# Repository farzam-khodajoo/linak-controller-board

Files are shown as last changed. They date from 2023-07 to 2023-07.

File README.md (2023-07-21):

## Introduction

Linak Controller Board is a small form factor pcb design which features ESP8266 for WIFI communication, this board is designed to control Hospital Bed with quad DC motors. 
(Kicad V6)

Each Motor uses 2 relays to change polarity and reverse rotation, also a linear voltage regulator is featured to power NodeMcu v3 board with small SPI pin connector on the side as extra utiltiy.

you can download schematic [here](https://github.com/farzam-khodajoo/linak-controller-board/blob/master/prints/Linak-controller.pdf).

## 3D views

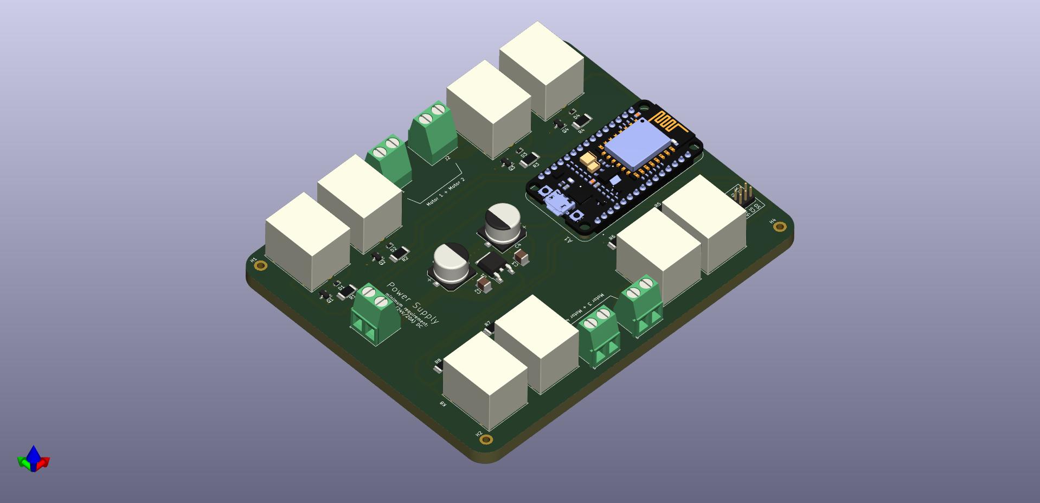
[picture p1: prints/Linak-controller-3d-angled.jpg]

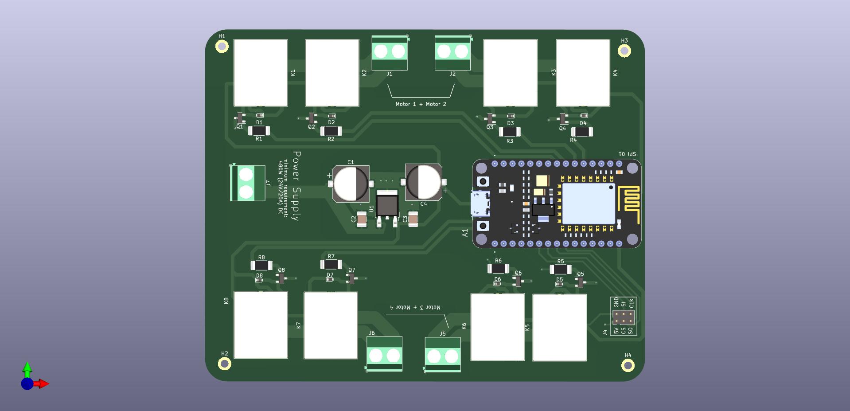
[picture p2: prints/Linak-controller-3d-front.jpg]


## PCB 
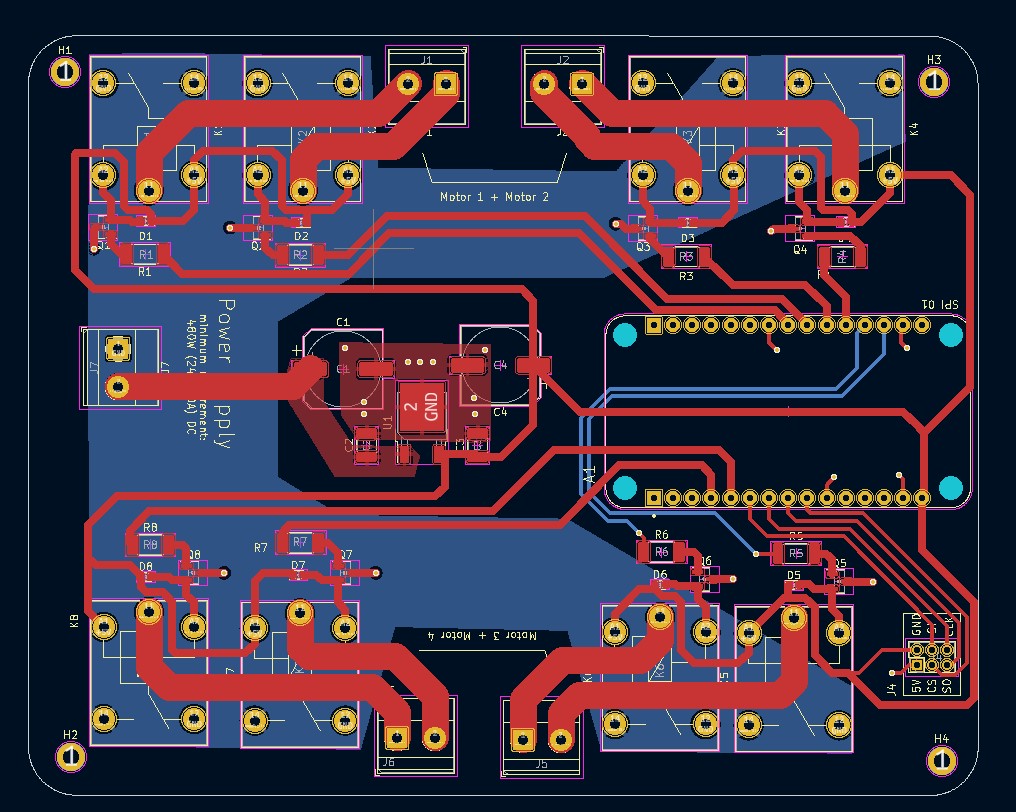
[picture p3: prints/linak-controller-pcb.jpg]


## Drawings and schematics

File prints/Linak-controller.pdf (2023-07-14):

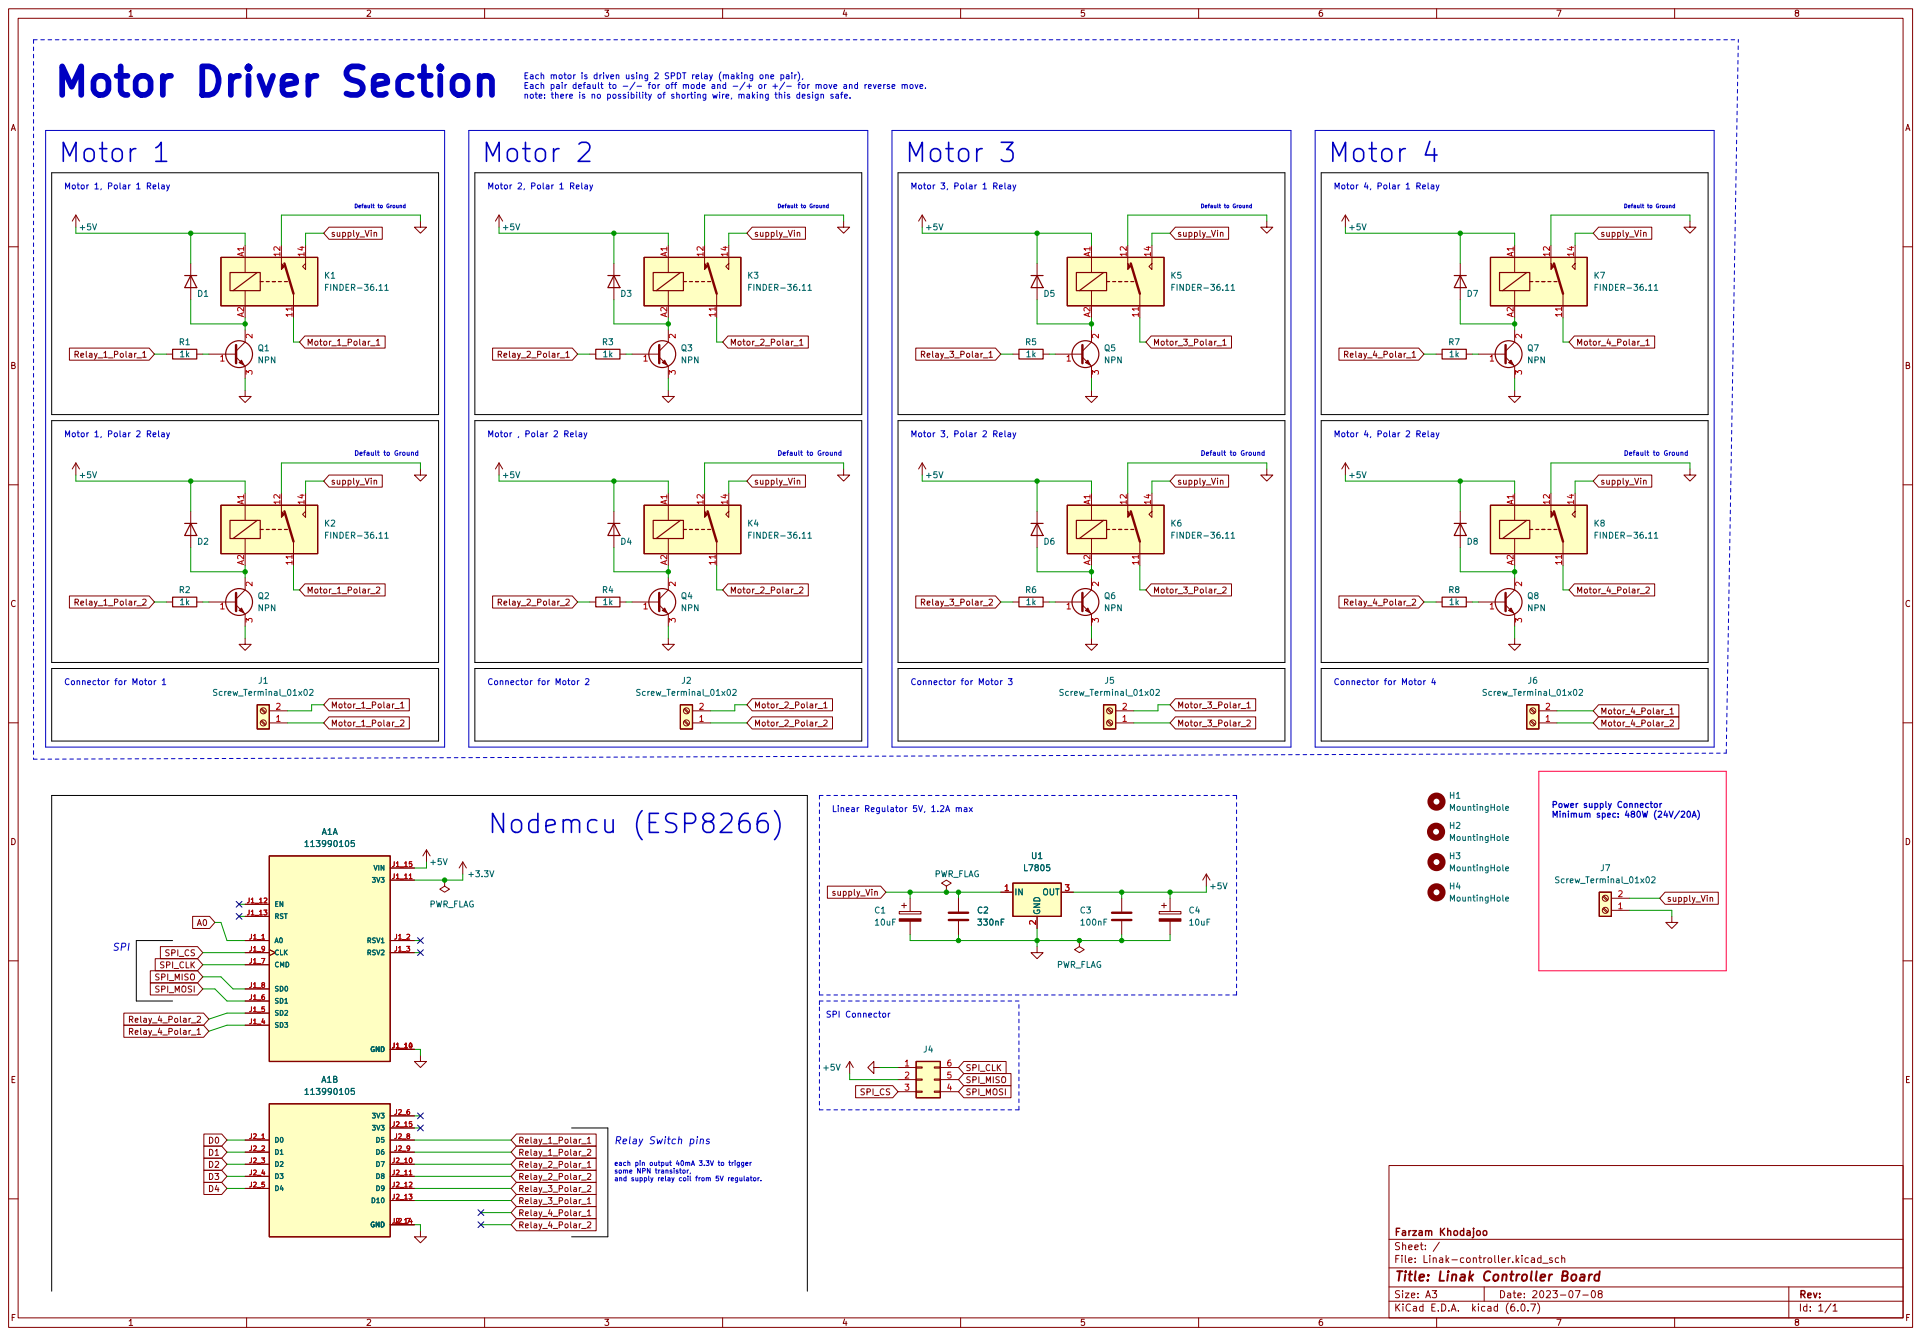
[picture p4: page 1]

Each pair default to -/- for off mode and -/+ or +/- for move and reverse move.
note: there is no possibility of shorting wire, making this design safe.
Motor 2

File: Linak-controller.kicad_sch Sheet: / Farzam Khodajoo H3MountingHole R6

each pin output 40mA 3.3V to trigger some NPN transistor, and supply relay coil from 5V regulator. Relay Switch pins

Id: 1/1 Title: Linak Controller Board

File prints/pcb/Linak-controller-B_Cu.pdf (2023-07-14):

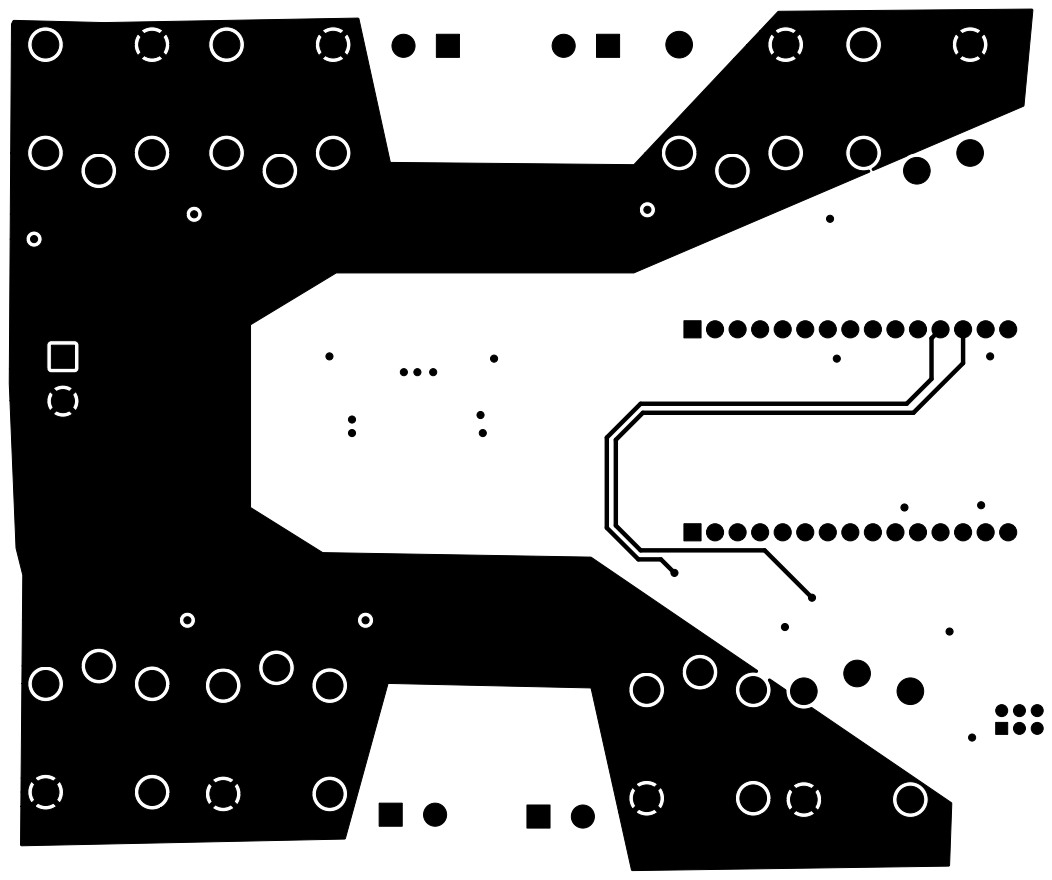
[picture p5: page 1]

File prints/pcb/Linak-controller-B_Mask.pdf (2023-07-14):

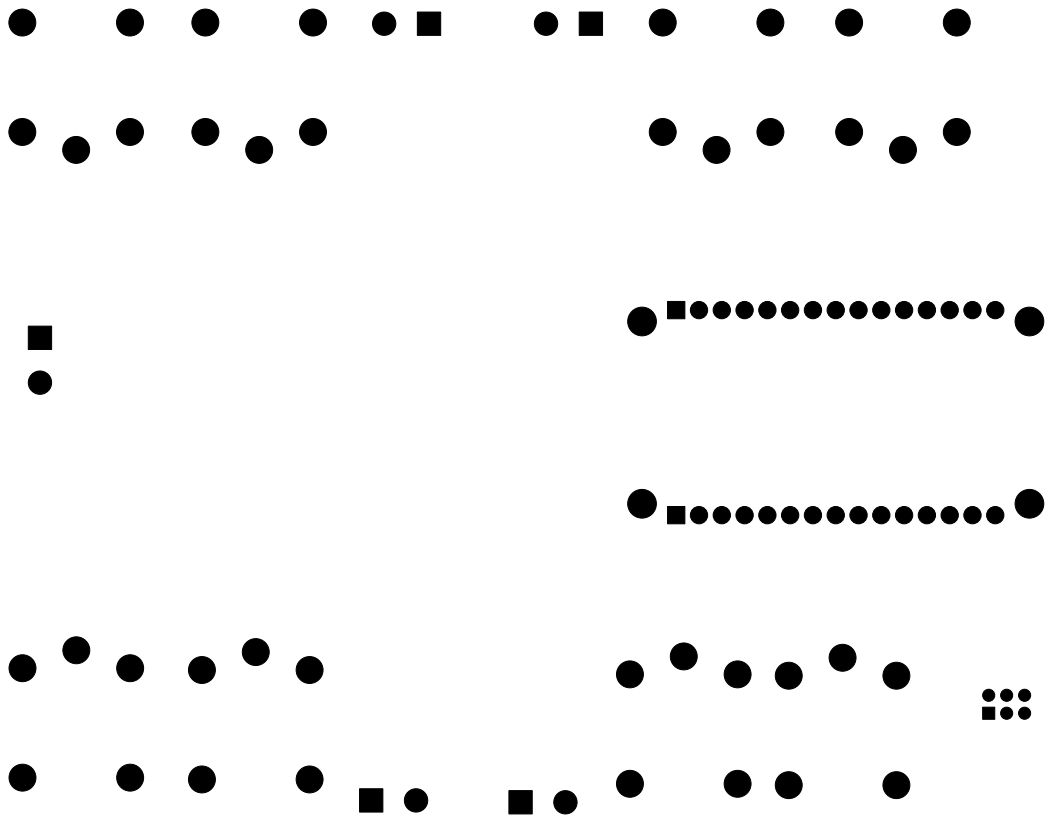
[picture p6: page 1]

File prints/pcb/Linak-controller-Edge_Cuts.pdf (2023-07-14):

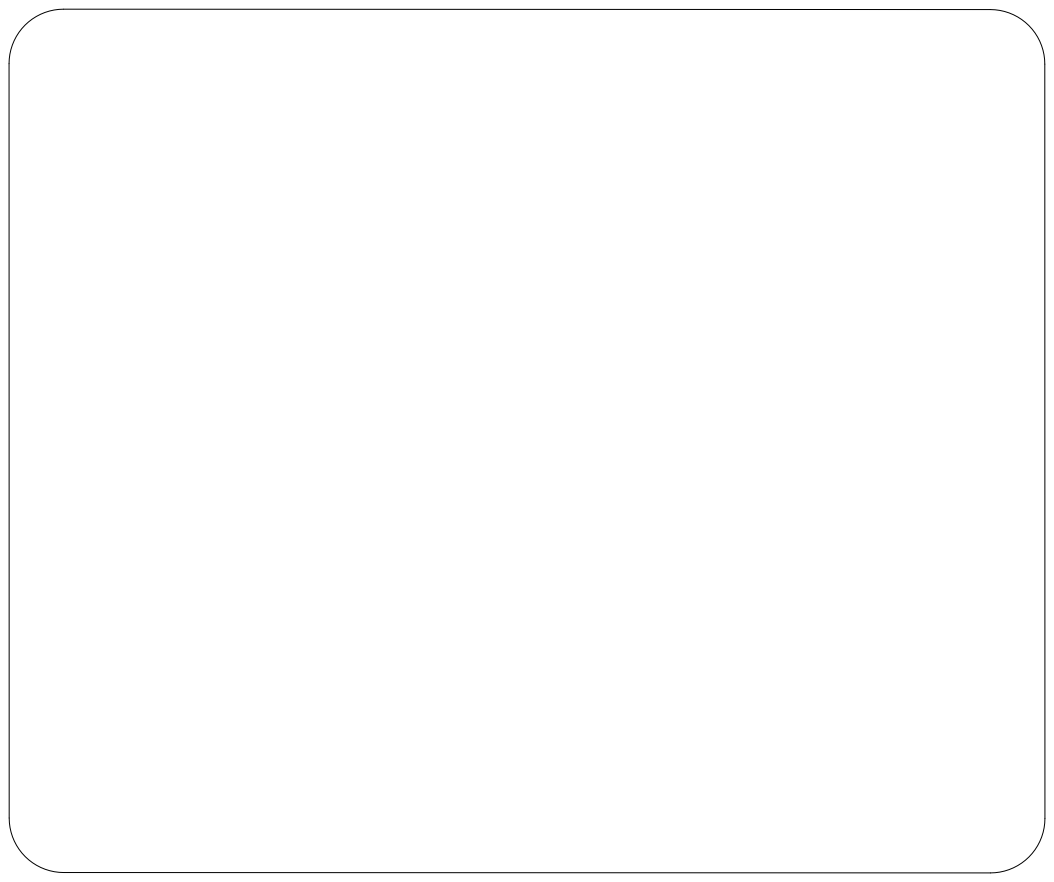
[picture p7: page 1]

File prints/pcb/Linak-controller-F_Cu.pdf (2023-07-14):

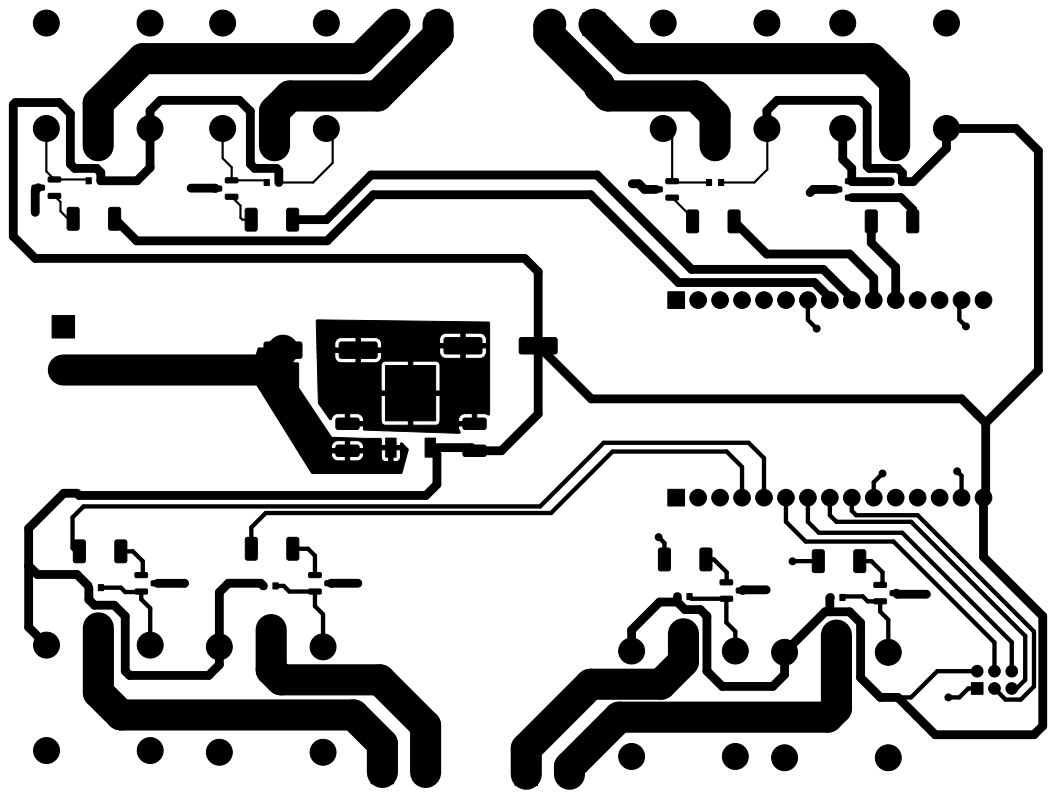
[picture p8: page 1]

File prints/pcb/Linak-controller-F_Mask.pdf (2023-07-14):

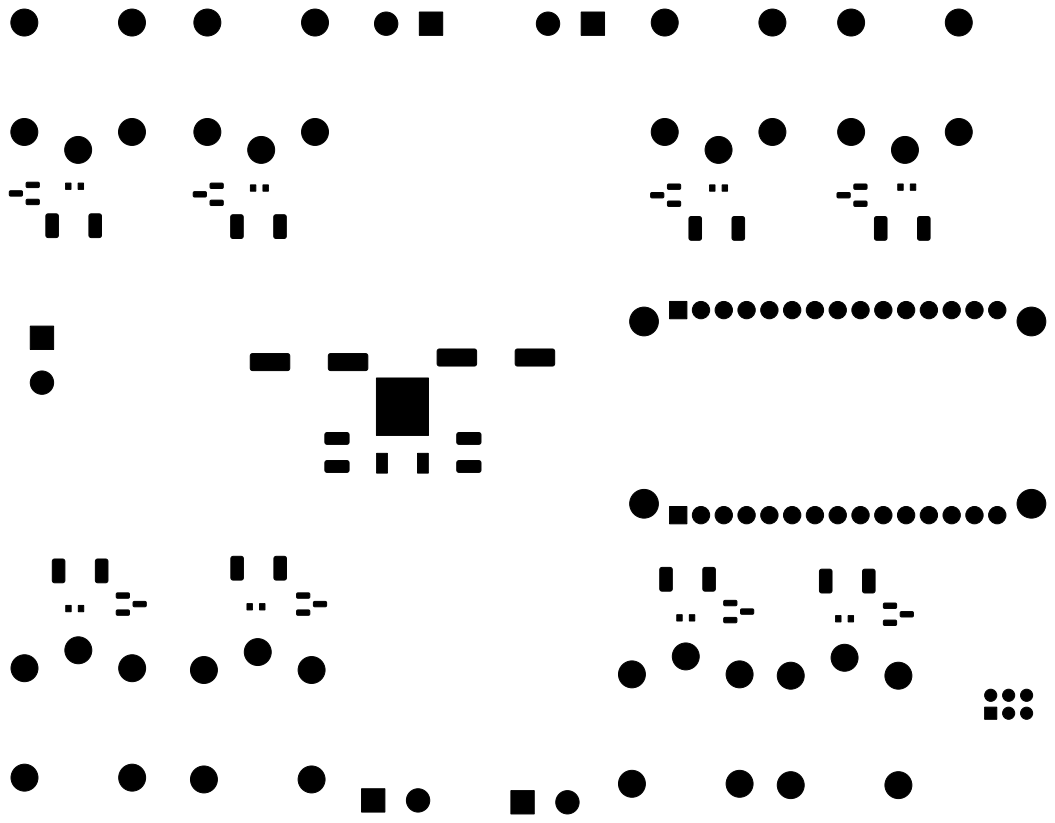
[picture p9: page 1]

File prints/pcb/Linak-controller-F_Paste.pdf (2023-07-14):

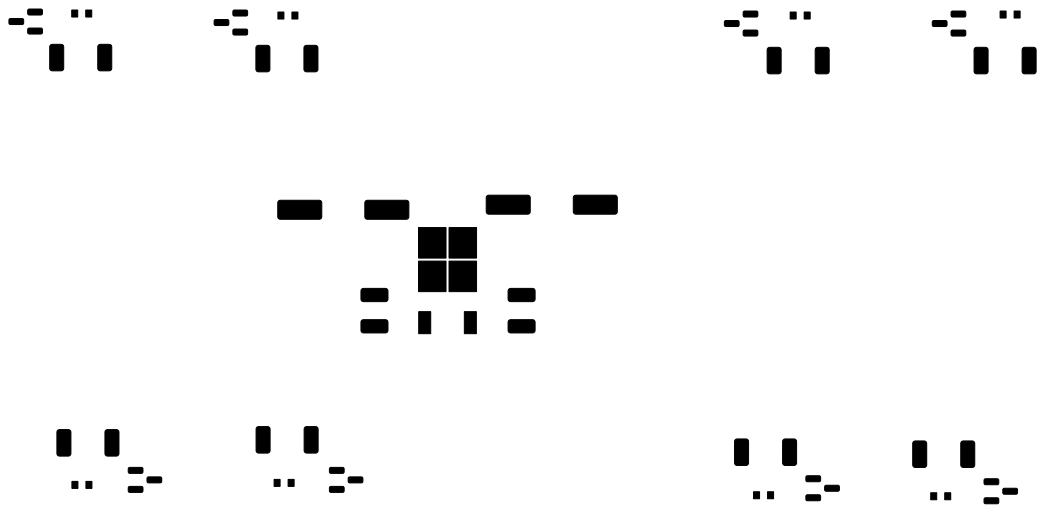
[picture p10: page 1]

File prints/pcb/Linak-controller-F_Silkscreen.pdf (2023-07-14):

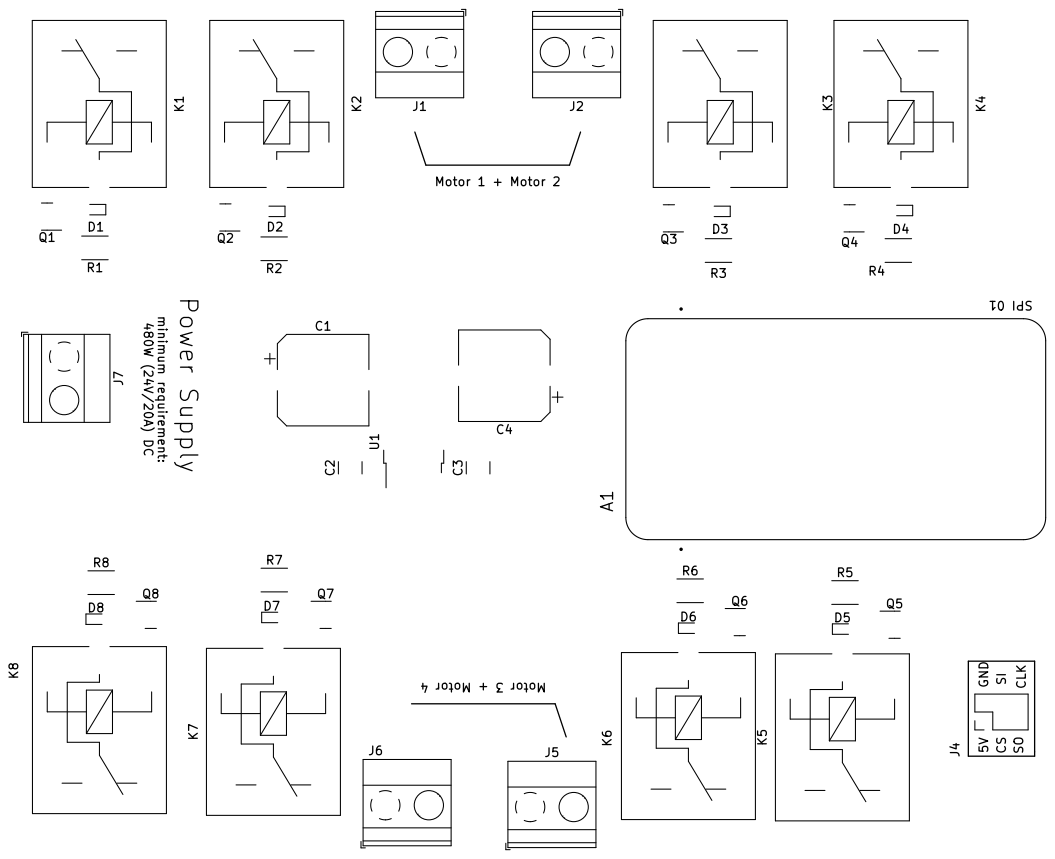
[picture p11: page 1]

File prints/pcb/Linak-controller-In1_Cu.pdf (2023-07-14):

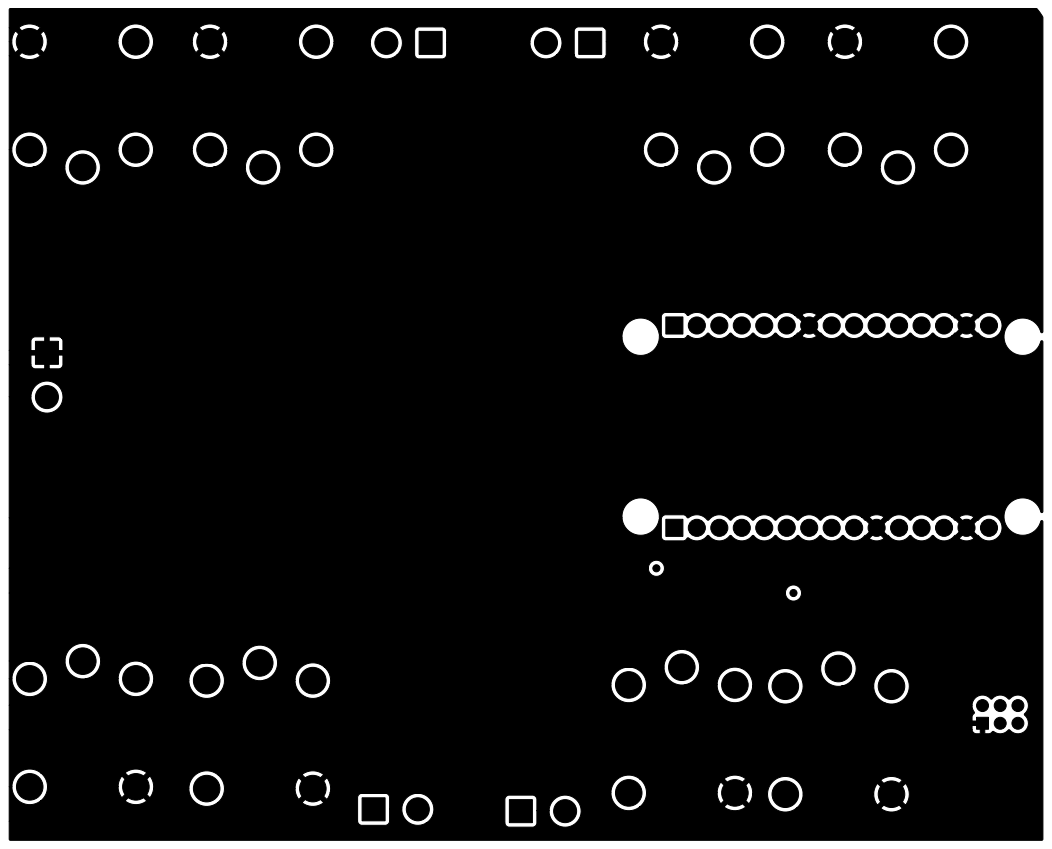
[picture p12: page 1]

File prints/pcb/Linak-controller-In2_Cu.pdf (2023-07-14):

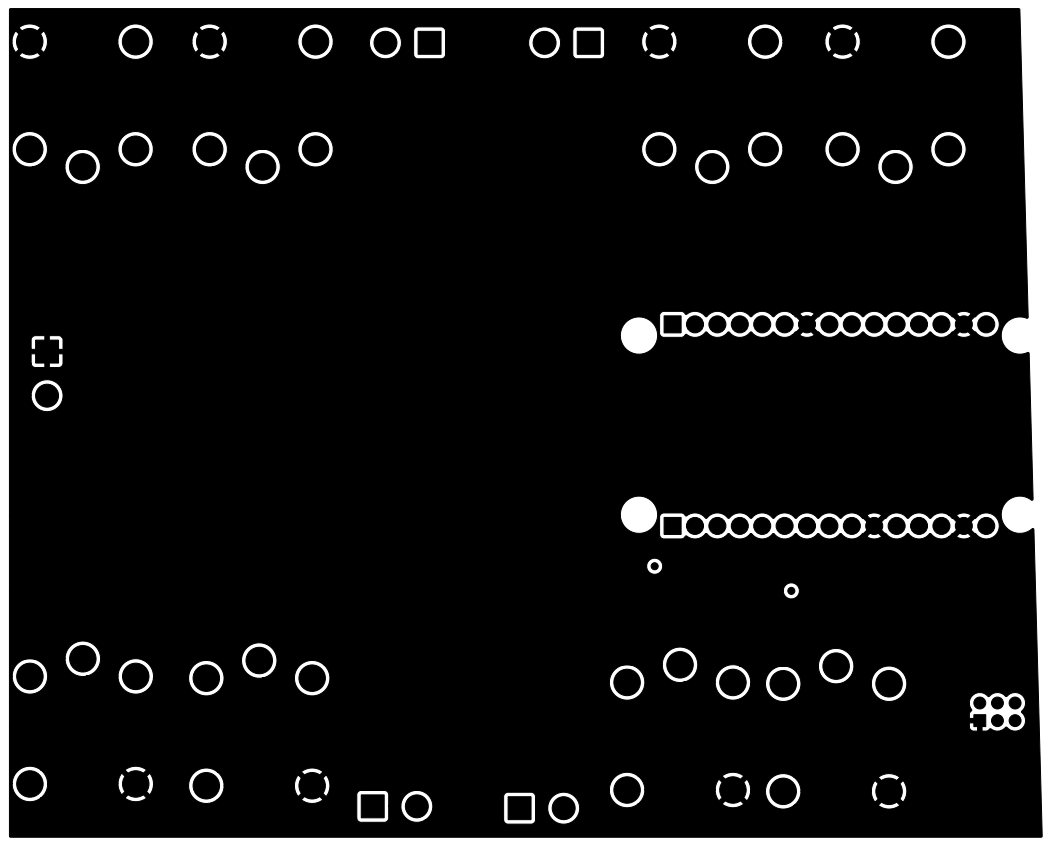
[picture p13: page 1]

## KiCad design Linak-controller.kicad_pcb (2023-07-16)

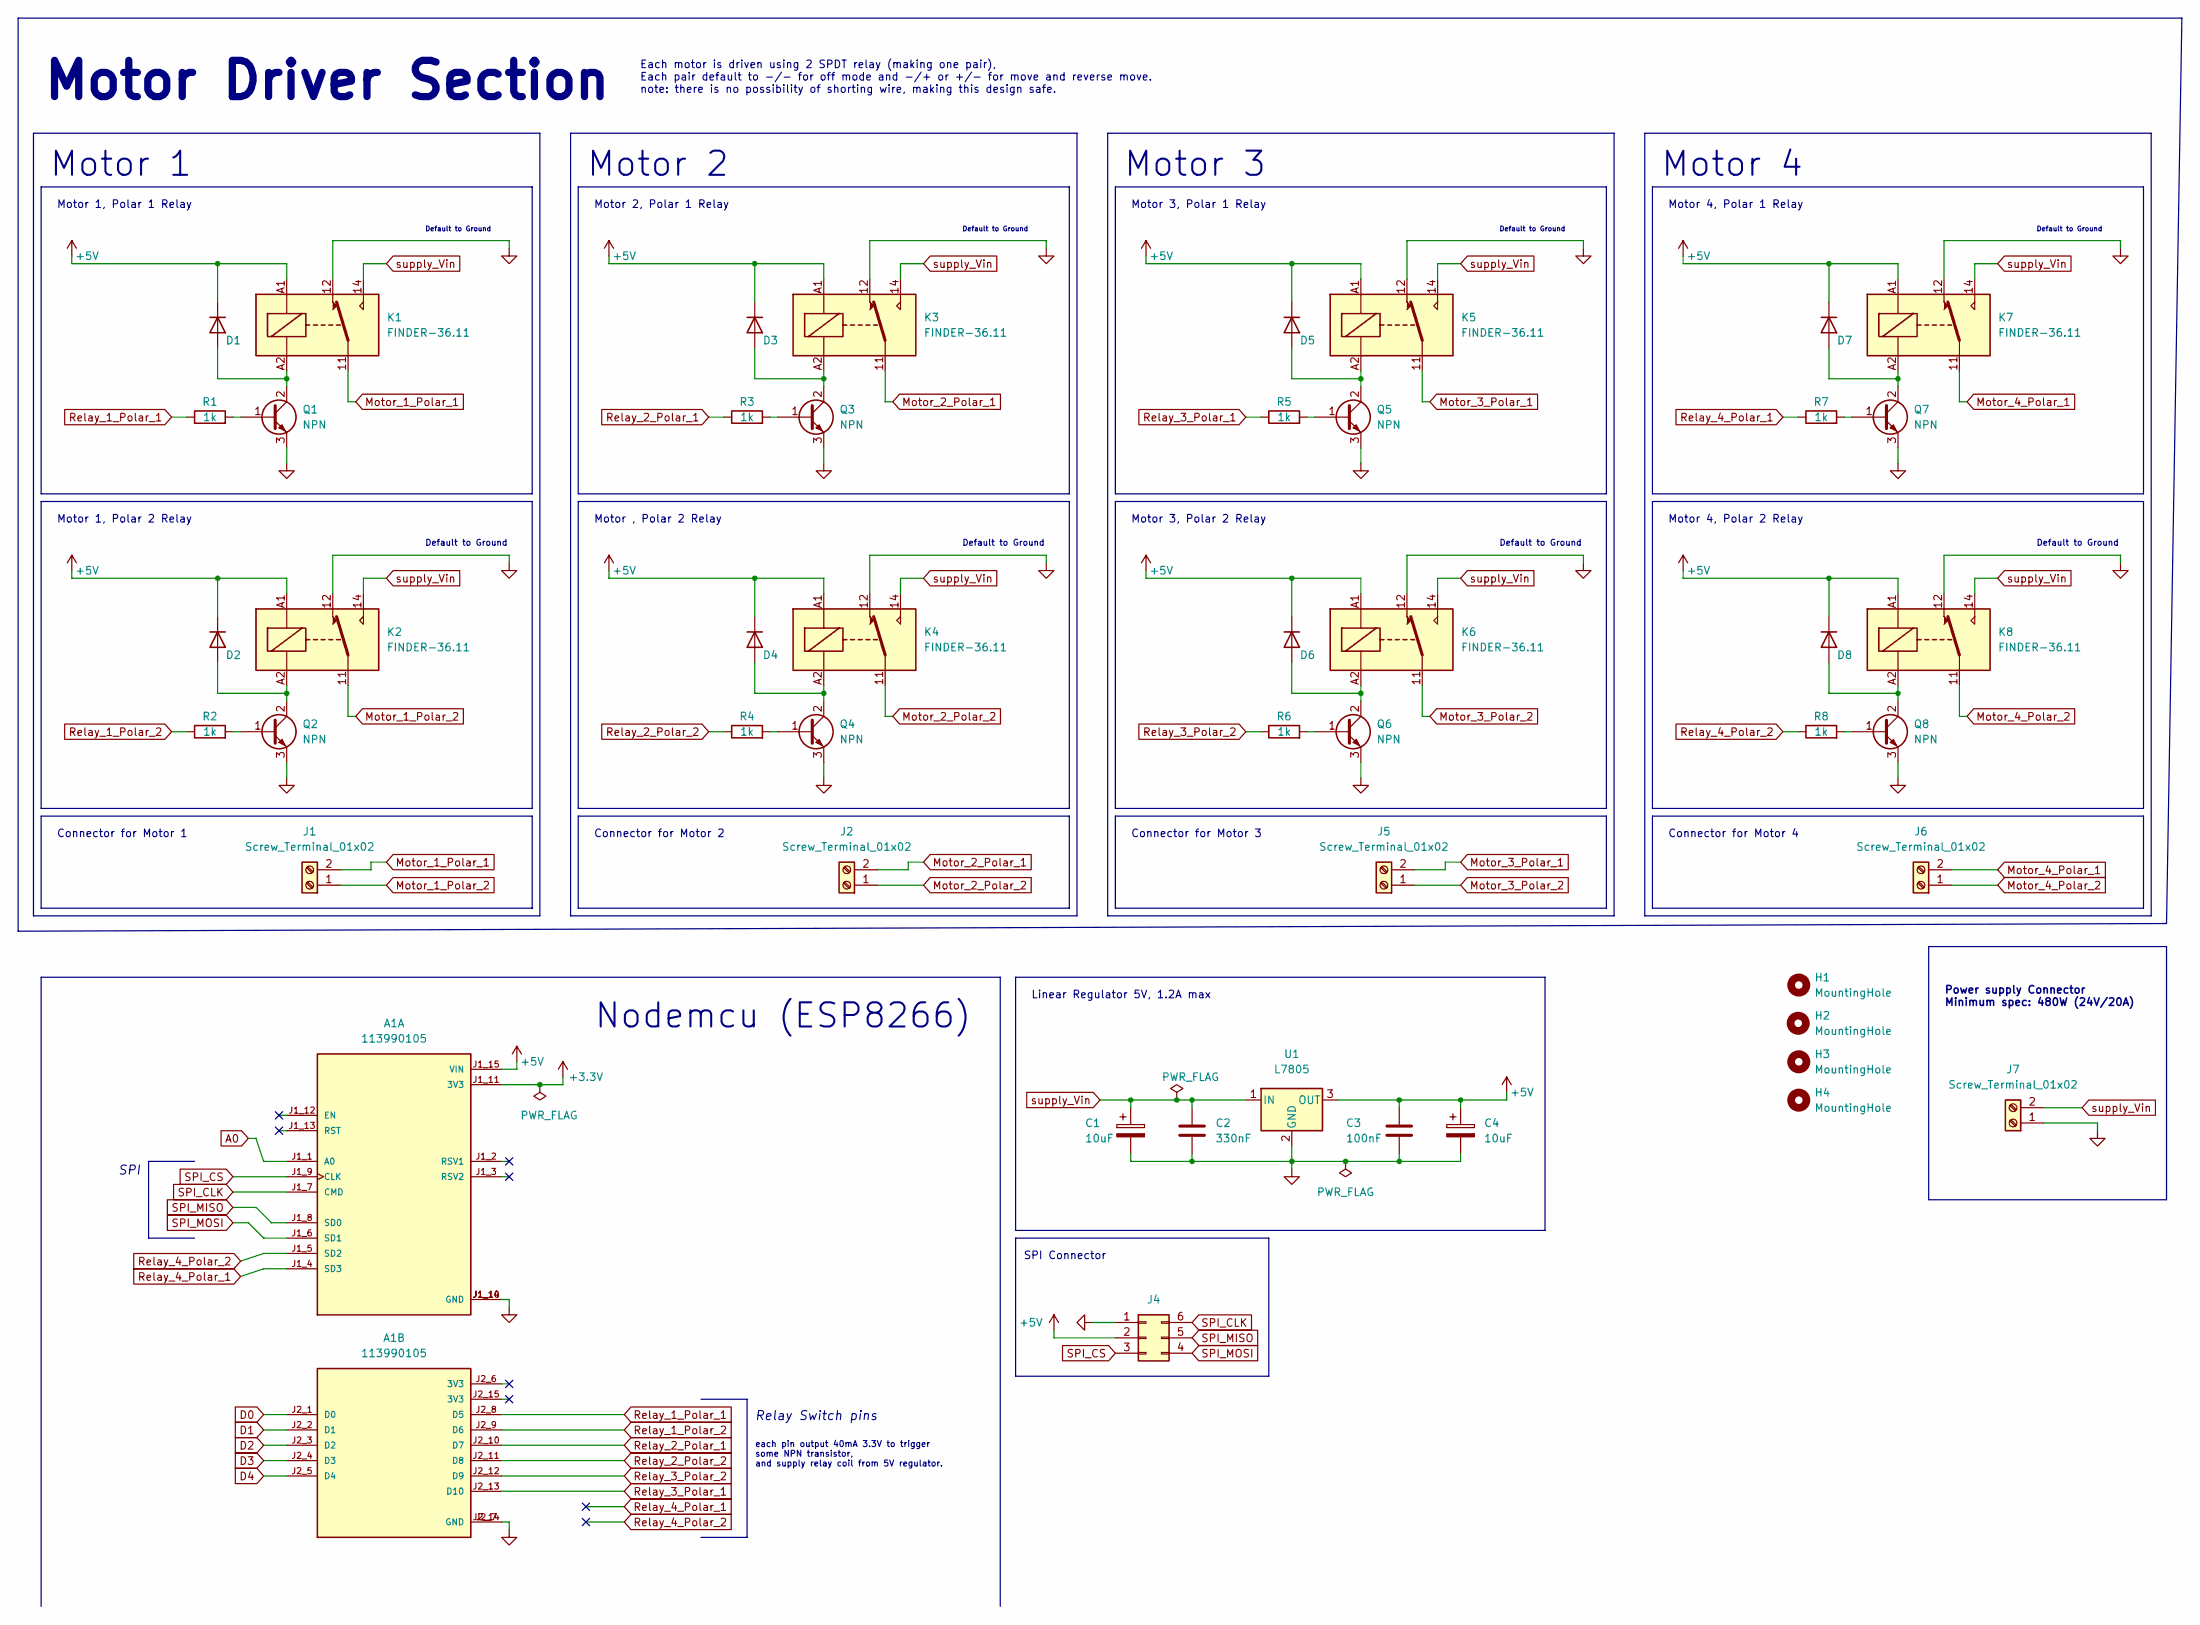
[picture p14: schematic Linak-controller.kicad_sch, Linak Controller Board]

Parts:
A1: 113990105; SEEED_NodemcuV3; PARTREV N/A
C1, C4: 10uF; CP_Elec_10x7.9
C2: 330nF; C_1210_3225Metric_Pad1.33x2.70mm_HandSolder
C3: 100nF; C_1210_3225Metric_Pad1.33x2.70mm_HandSolder
D1, D2, D3, D4, D5, D6, D7, D8: 1N914WT; D_SOD-523
H1, H2, H3, H4: MountingHole; MountingHole_2.2mm_M2_DIN965_Pad
J1, J2, J5, J6, J7: Screw_Terminal_01x02; TerminalBlock_Phoenix_MKDS-1,5-2_1x02_P5.00mm_Horizontal
J4: Conn_02x03_Counter_Clockwise; PinHeader_2x03_P2.00mm_Vertical
K1, K2, K3, K4, K5, K6, K7, K8: FINDER-36.11; Relay_SPDT_Finder_36.11
Q1, Q2, Q3, Q4, Q5, Q6, Q7, Q8: NPN; SOT-23
R1, R2, R3, R4, R5, R6, R7, R8: 1k; R_2010_5025Metric_Pad1.40x2.65mm_HandSolder
U1: L7805; TO-252-2

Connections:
+3.3V: A1.J1_11 (3V3)
+5V: A1.J1_15 (VIN), C3.1, C4.1, D1.1 (K), D2.1 (K), D3.1 (K), D4.1 (K), D5.1 (K), D6.1 (K), D7.1 (K), D8.1 (K), J4.2, K1.A1, K2.A1, K3.A1, K4.A1, K5.A1, K6.A1, K7.A1, K8.A1, U1.3 (OUT)
A0: A1.J1_1 (A0)
D0: A1.J2_1 (D0)
D1: A1.J2_2 (D1)
D2: A1.J2_3 (D2)
D3: A1.J2_4 (D3)
D4: A1.J2_5 (D4)
GND: A1.J1_10 (GND), A1.J1_14 (GND), A1.J2_7 (GND), A1.J2_14 (GND), C1.2, C2.2, C3.2, C4.2, J4.1, J7.1, K1.12, K2.12, K3.12, K4.12, K5.12, K6.12, K7.12, K8.12, Q1.3 (E), Q2.3 (E), Q3.3 (E), Q4.3 (E), Q5.3 (E), Q6.3 (E), Q7.3 (E), Q8.3 (E), U1.2 (GND)
Motor_1_Polar_1: J1.2, K1.11
Motor_1_Polar_2: J1.1, K2.11
Motor_2_Polar_1: J2.2, K3.11
Motor_2_Polar_2: J2.1, K4.11
Motor_3_Polar_1: J5.2, K5.11
Motor_3_Polar_2: J5.1, K6.11
Motor_4_Polar_1: J6.2, K7.11
Motor_4_Polar_2: J6.1, K8.11
unnamed: D1.2 (A), K1.A2, Q1.2 (C)
unnamed: D2.2 (A), K2.A2, Q2.2 (C)
unnamed: D3.2 (A), K3.A2, Q3.2 (C)
unnamed: D4.2 (A), K4.A2, Q4.2 (C)
unnamed: D5.2 (A), K5.A2, Q5.2 (C)
unnamed: D6.2 (A), K6.A2, Q6.2 (C)
unnamed: D7.2 (A), K7.A2, Q7.2 (C)
unnamed: D8.2 (A), K8.A2, Q8.2 (C)
unnamed: Q1.1 (B), R1.2
unnamed: Q2.1 (B), R2.2
unnamed: Q3.1 (B), R3.2
unnamed: Q4.1 (B), R4.2
unnamed: Q5.1 (B), R5.2
unnamed: Q6.1 (B), R6.2
unnamed: Q7.1 (B), R7.2
unnamed: Q8.1 (B), R8.2
Relay_1_Polar_1: A1.J2_8 (D5), R1.1
Relay_1_Polar_2: A1.J2_9 (D6), R2.1
Relay_2_Polar_1: A1.J2_10 (D7), R3.1
Relay_2_Polar_2: A1.J2_11 (D8), R4.1
Relay_3_Polar_1: A1.J2_13 (D10), R5.1
Relay_3_Polar_2: A1.J2_12 (D9), R6.1
Relay_4_Polar_1: A1.J1_4 (SD3), R7.1
Relay_4_Polar_2: A1.J1_5 (SD2), R8.1
SPI_CLK: A1.J1_7 (CMD), J4.6
SPI_CS: A1.J1_9 (CLK), J4.3
SPI_MISO: A1.J1_8 (SD0), J4.5
SPI_MOSI: A1.J1_6 (SD1), J4.4
supply_Vin: C1.1, C2.1, J7.2, K1.14, K2.14, K3.14, K4.14, K5.14, K6.14, K7.14, K8.14, U1.1 (IN)

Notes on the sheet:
Motor 3, Polar 1 Relay
Motor 3
Connector for Motor 1
Motor 1
Motor 1, Polar 1 Relay
Each motor is driven using 2 SPDT relay (making one pair), Each pair default to -/- for off mode and -/+ or +/- for move and reverse move. note: there is no possibility of shorting wire, making this design safe.
Relay Switch pins
SPI Connector
Motor , Polar 2 Relay
Motor Driver Section
Default to Ground
Motor 2, Polar 1 Relay
Connector for Motor 4
Motor 4
Nodemcu (ESP8266)
Connector for Motor 2
SPI
Motor 1, Polar 2 Relay
Connector for Motor 3
Motor 4, Polar 1 Relay
Motor 3, Polar 2 Relay
Power supply Connector Minimum spec: 480W (24V/20A)
Linear Regulator 5V, 1.2A max
Motor 4, Polar 2 Relay
each pin output 40mA 3.3V to trigger some NPN transistor, and supply relay coil from 5V regulator.
Motor 2

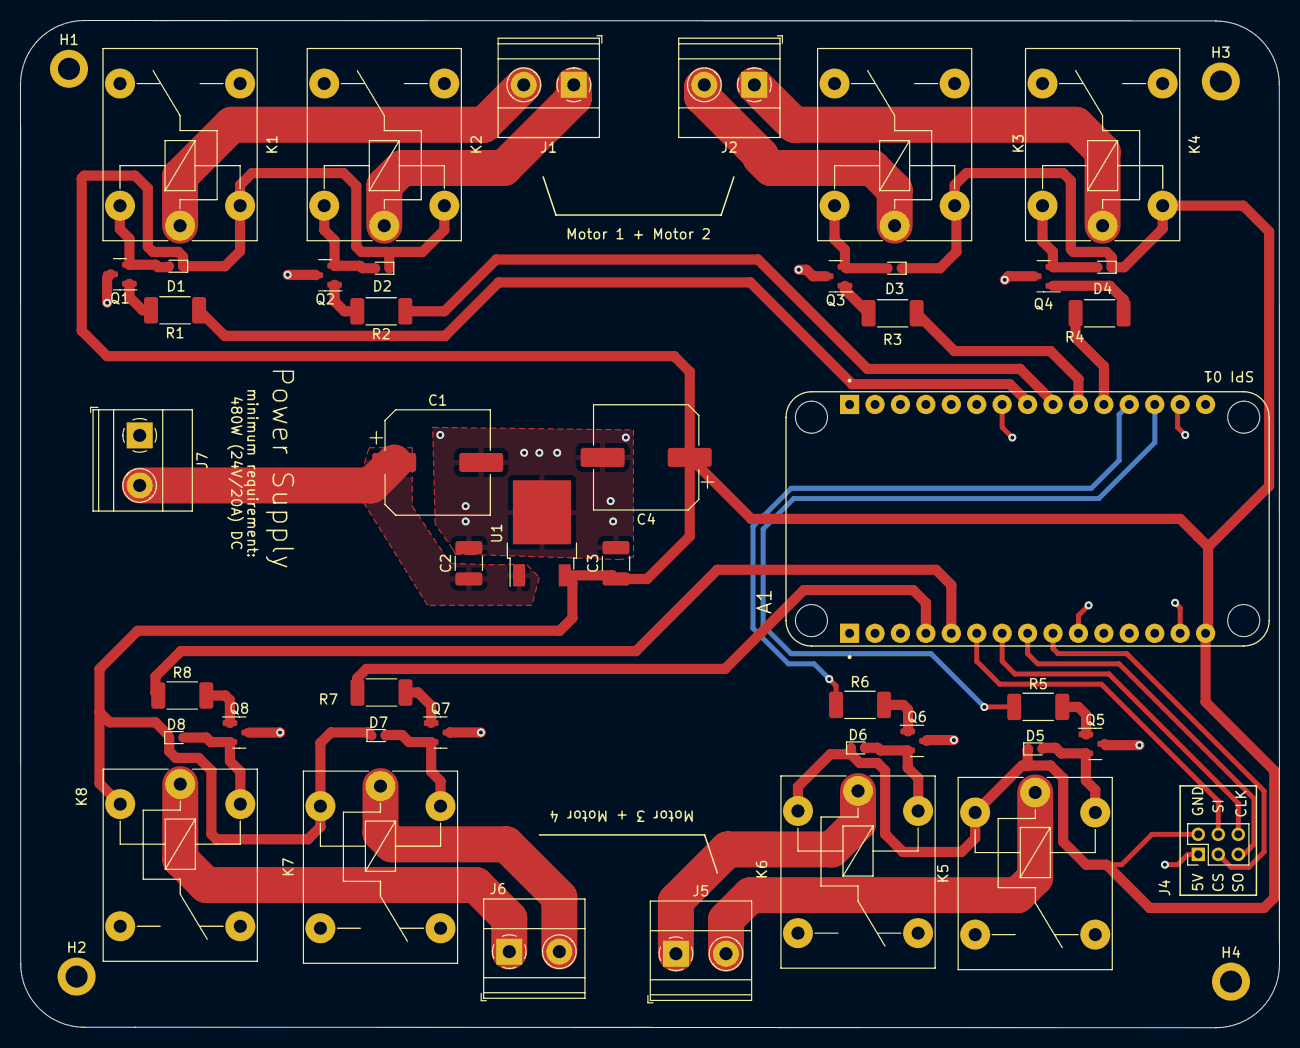
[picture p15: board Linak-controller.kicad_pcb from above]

Board: 4 copper layers, 125.8 x 100.6 mm, 48 parts (0 on the bottom side), 39 nets.

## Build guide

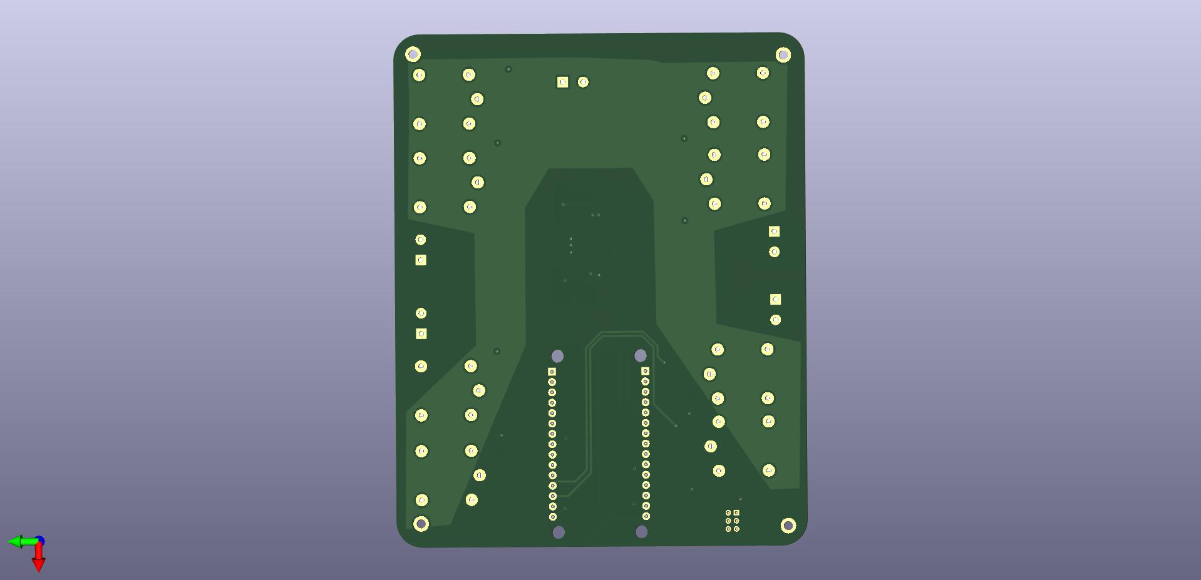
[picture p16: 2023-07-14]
prints/Linak-controller-3d-bottom.jpg

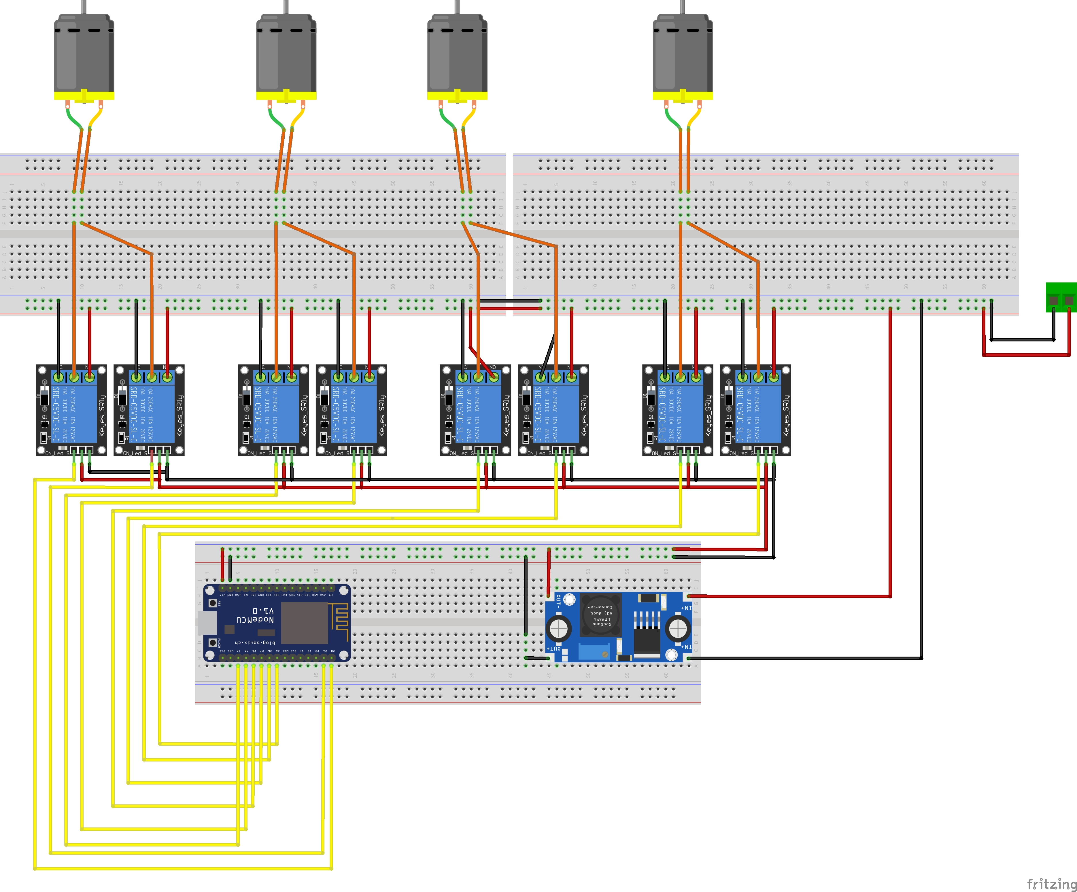
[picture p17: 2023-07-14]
prints/on_breadboard_prototype.jpg

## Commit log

2023-07-14 fix lazy mistakes
    [Linak-controller.kicad_pcb]
2023-07-16 fix some imperfections
    [Linak-controller.kicad_pcb]
2023-07-16 update pcb image
    [Linak-controller.kicad_pcb]
